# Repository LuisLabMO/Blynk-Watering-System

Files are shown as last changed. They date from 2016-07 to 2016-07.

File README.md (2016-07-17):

# Smart Modular Watering System using Blynk

I like plants, I like to be eco-friendly, love electronics, but how can I fit those things together? enters the **Smart Modular Watering System**.

Smart Modular Watering System using Blynk - Youtube (https://youtu.be/UPALH_MEa6o)

Using the [SparkFun ESP8266 Blynk Board](https://www.sparkfun.com/products/13794) with the [Blynk app](http://www.blynk.cc) you can build a system that monitors the level of the water reservoir and will water your plants automatically at the right moment.

> **It will help you save water!**

## Sensors data

Data collected from sensors is used to decide when is the right time to water the plants, to send alerts when the water reservoir is low and more:

* **Soil moisture sensor**: accurately measures the actual soil moisture.
* An **ultrasonic distance sensor** will measure the level of the water reservoir with good reliability.
* **UV sensor** data may help deciding whether your plant needs more shadow or direct sunlight.
* **Temperature** and **humidity** sensors can also help deciding about critical conditions for your plants.

## Operation - The Blynk App

The Blynk app can be used to monitor in real time the data collected by the sensors:
* Plot the UV index.
* Monitor the water level, temperature, humidity, soil moisture in real time.
* Check the status of the irrigation system (On/Off) - **H2O Led**.

Some parameters of the system can be modified by using the Blynk app too:
* **Water level threshold**: if the water level is above¹ this number, the app will send a warning.
* **Soil moisture threshold**: the system will turn On the irrigation if the current soil moisture is below this number.
* **Watering interval _(in hours)_**: how often the system will irrigate -if conditions require it-.
* **Watering time _(in seconds)_**: duration of the irrigation when activated.

> ¹Please note that the water level sensor measures the distance between the top of the container and the surface of the water. So a higher number means a lower water level.

## Make it Modular, Make it Smarter

The **Smart Modular Watering System** has a very simple implementation, but there is lot of room for improvement. Some other features can be added to the **Smart Modular Watering System** with some more work, these are just a few examples:

* The **UV sensor** data can also be used to decide at what times of the day to stop watering. *Maybe stop watering at night?*
* The data collected can be analyzed to predict the water usage. e.g.: *How much water your plants will need before your next trip.*
* Add a solar panel, charge your batteries with it and show the world that you care about the Environment!.

## Repository Contents

* [/3D_Models](https://github.com/LuisLabMO/Blynk-Watering-System/tree/master/3D_Models) - SketchUp and **.STL** files
* [/ATtiny45_HC-SR04_to_I2C_Source_Code](https://github.com/LuisLabMO/Blynk-Watering-System/tree/master/ATtiny45_HC-SR04_to_I2C_Source_Code) - Source code for the ATtiny45 used to convert the data from ultrasonic distance sensor to I2C.
* [/Blynk_Board_Source_Code](https://github.com/LuisLabMO/Blynk-Watering-System/tree/master/Blynk_Board_Source_Code) - Source code for the [SparkFun ESP8266 Blynk Board](https://www.sparkfun.com/products/13794)
* [/Hardware](https://github.com/LuisLabMO/Blynk-Watering-System/tree/master/Hardware) - Eagle design files: **.BRD**, **.SCH**

## More Information

For more information visit the project page on [Hackster.io](https://www.hackster.io/lmortizg/smart-modular-watering-system-b571ec)

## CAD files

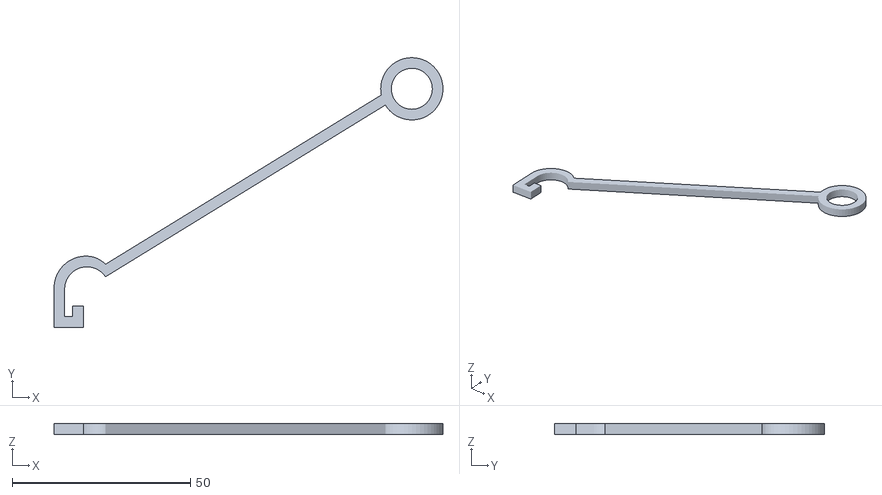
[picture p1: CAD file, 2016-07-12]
3D_Models/Tubing bracket for window planter.stl
109.2 x 75.7 x 3.00

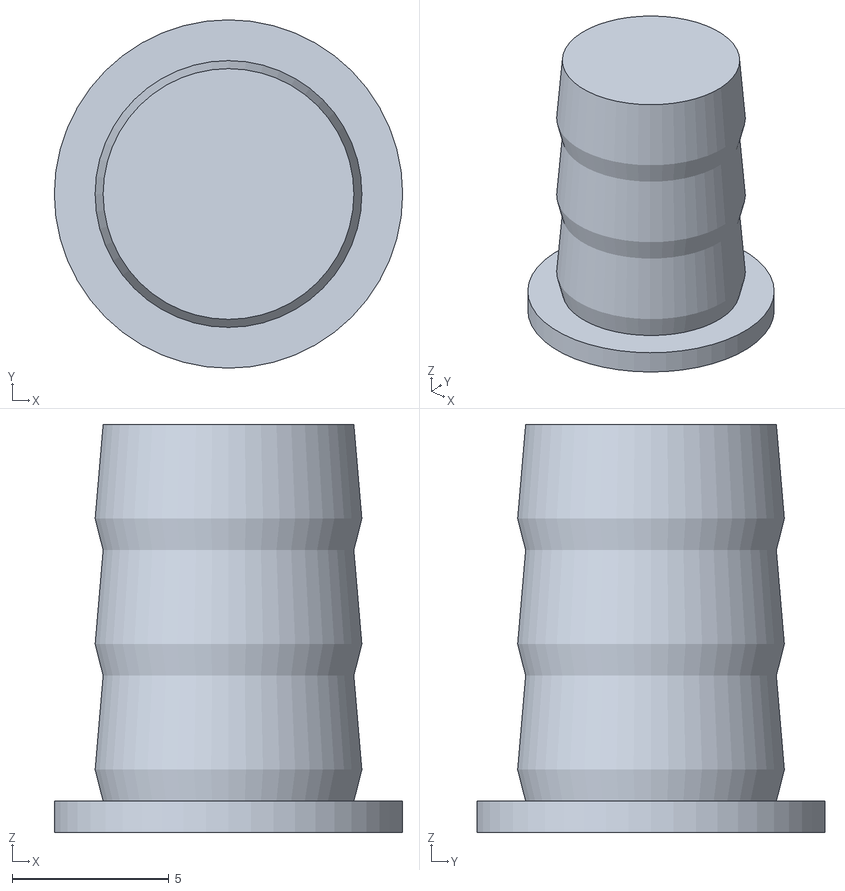
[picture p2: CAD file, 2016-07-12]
3D_Models/Clear Tube End Cap 5_16.stl
11.1 x 11.1 x 13.0

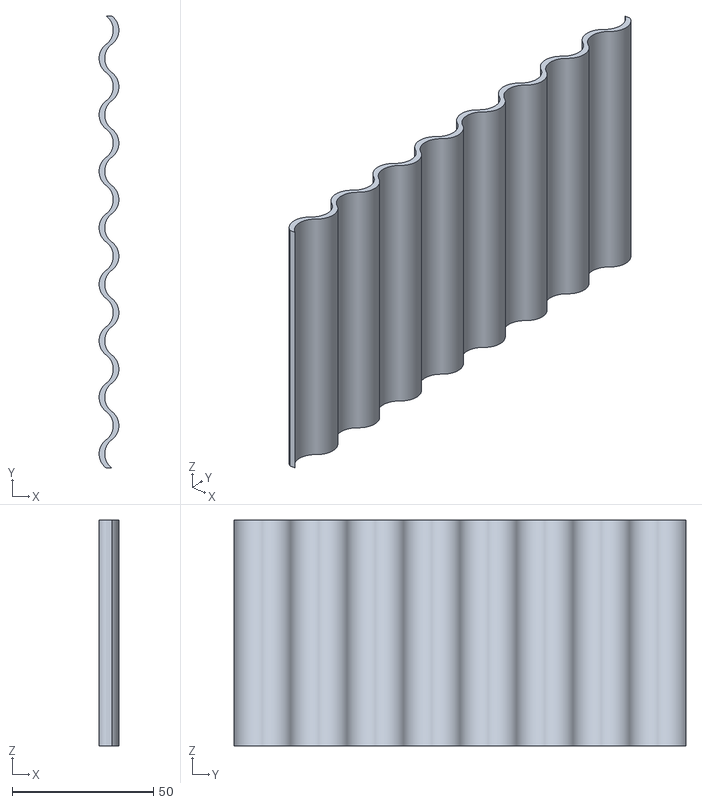
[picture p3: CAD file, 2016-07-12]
3D_Models/Blynk Smart Modular Water System roof.stl
7.00 x 160.0 x 80.0

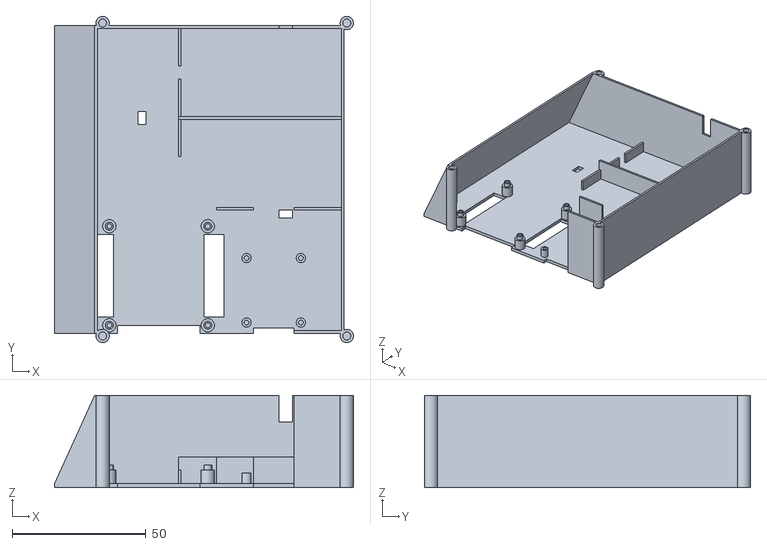
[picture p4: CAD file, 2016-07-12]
3D_Models/Blynk Smart Modular Water System mount.stl
111.8 x 122.0 x 34.5

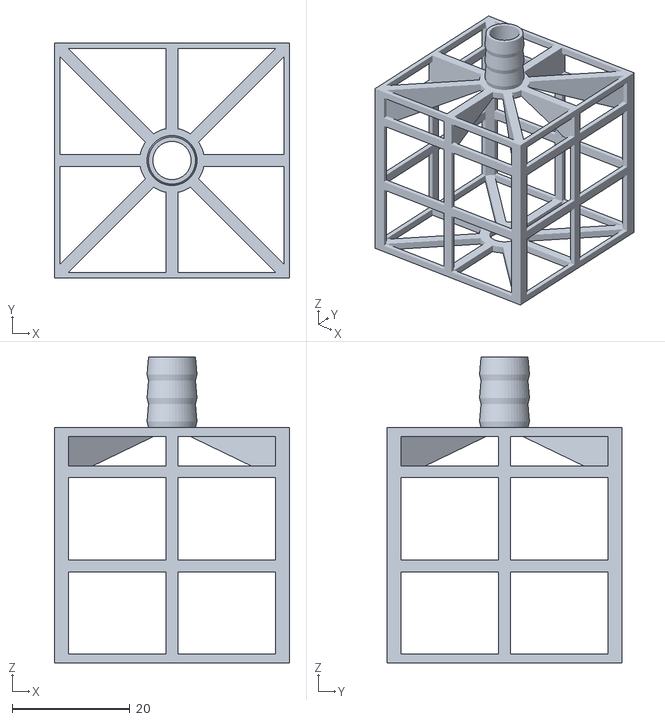
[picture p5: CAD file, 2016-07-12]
3D_Models/Cage cube for water filter 5_16.stl
40.0 x 40.0 x 52.0

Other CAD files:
3D_Models/Blynk Smart Modular Water System mount.skp
3D_Models/Blynk Smart Modular Water System roof.skp
3D_Models/Cage cube for water filter 5_16.skp
3D_Models/Clear Tube End Cap 5_16.skp
3D_Models/Tubing bracket for window planter.skp

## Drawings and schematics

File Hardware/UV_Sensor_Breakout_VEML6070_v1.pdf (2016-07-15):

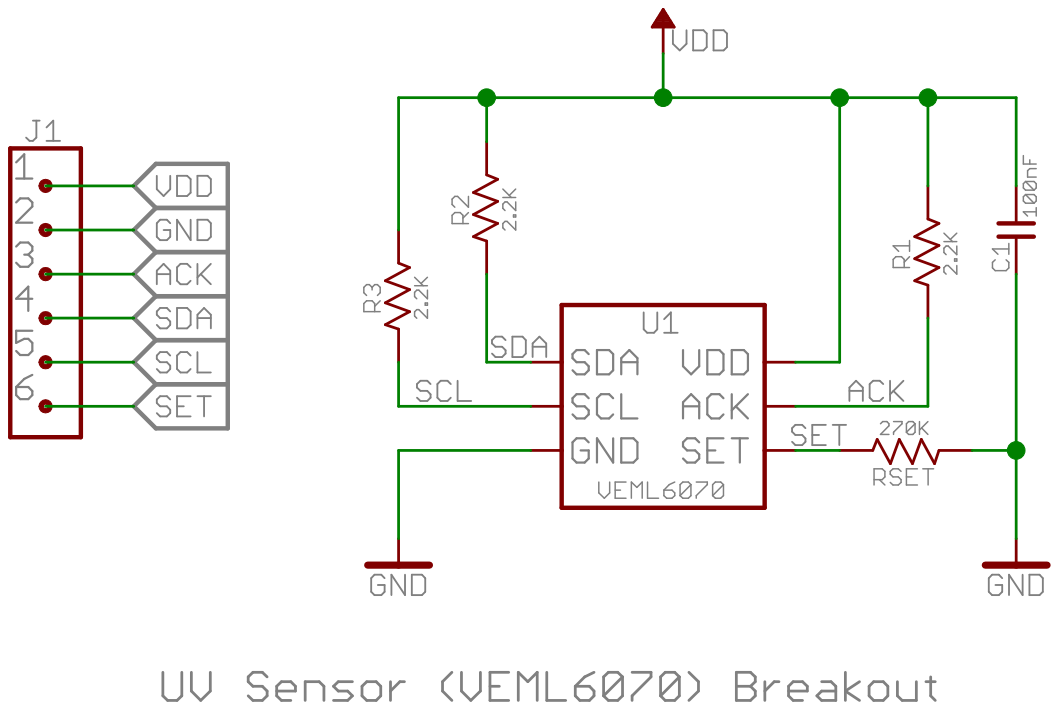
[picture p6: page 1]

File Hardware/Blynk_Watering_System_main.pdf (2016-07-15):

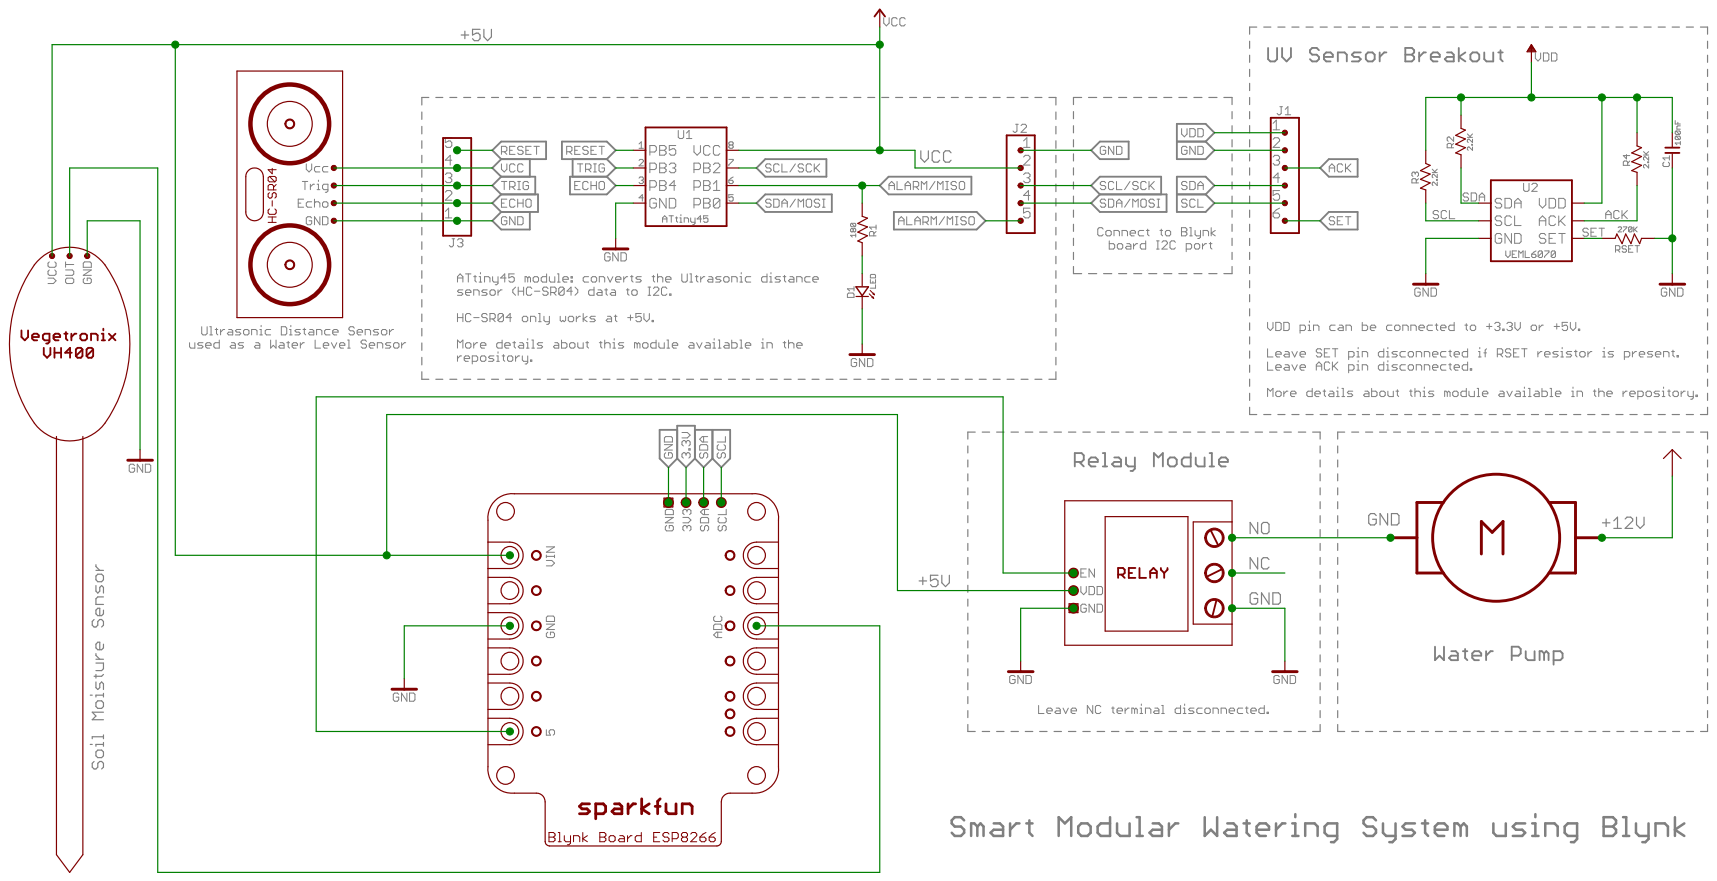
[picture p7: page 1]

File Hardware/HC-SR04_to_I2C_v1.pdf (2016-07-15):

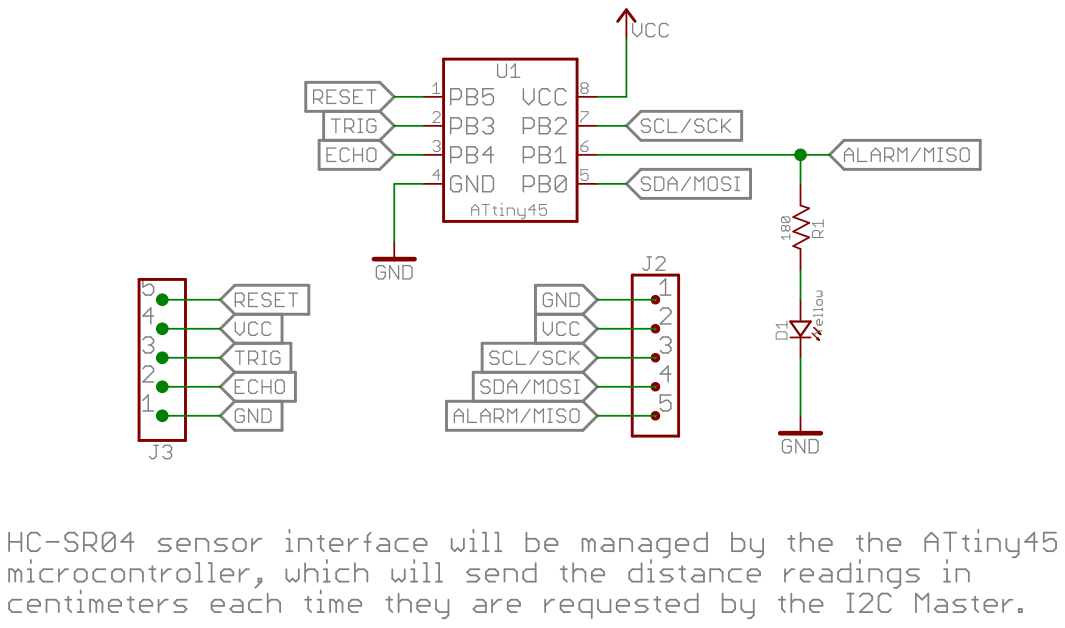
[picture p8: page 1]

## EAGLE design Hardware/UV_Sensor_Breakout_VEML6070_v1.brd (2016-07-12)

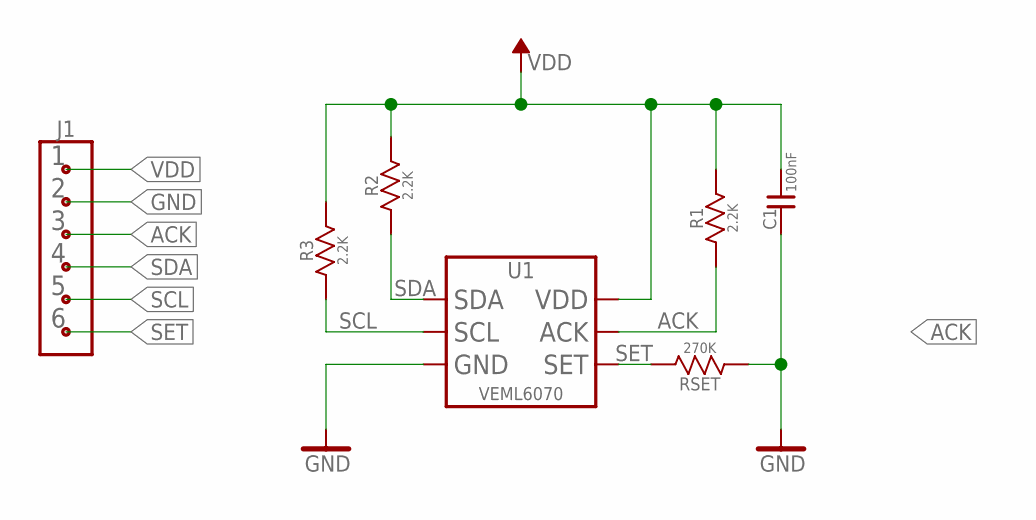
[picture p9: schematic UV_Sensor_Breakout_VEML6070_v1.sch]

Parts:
C1: 100nF; 0603[1608]
J1: PIN_HEADER_1X06_0.1"_STR_G[2]_PTH
R1, R2, R3: 2.2K; 0603[1608]
RSET: 270K; 0603[1608]
U1: VEML6070; OPLGA

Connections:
ACK: J1.3, R1.1, U1.2 (ACK)
GND: C1.1, J1.2, RSET.1, U1.1 (GND)
SCL: J1.5, R3.1, U1.5 (SCL)
SDA: J1.4, R2.1, U1.3 (SDA)
SET: J1.6, RSET.2, U1.4 (SET)
VDD: C1.2, J1.1, R1.2, R2.2, R3.2, U1.6 (VDD)

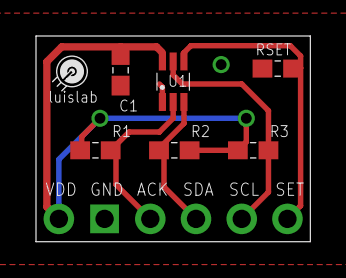
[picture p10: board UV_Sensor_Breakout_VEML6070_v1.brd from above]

Board: 2 copper layers, 15.2 x 11.4 mm, 7 parts (1 on the bottom side), 6 nets.

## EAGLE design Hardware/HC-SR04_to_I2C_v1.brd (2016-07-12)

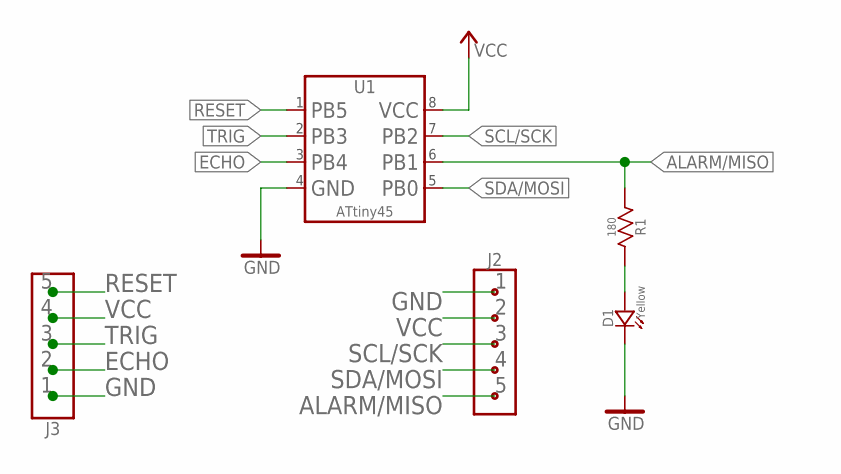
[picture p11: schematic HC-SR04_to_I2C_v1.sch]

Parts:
D1: Yellow; 0805[2012]
J2, J3: PIN_HEADER_1X05_0.1"_STR_G[1]_PTH
R1: 180; 0603[1608]
U1: ATtiny45; TSSOP_MO-153-AC

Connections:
ALARM/MISO: J2.5, R1.1, U1.6 (PB1)
ECHO: J3.2, U1.3 (PB4)
GND: D1.-, J2.1, J3.1, U1.4 (GND)
unnamed: D1.+, R1.2
RESET: J3.5, U1.1 (PB5)
SCL/SCK: J2.3, U1.7 (PB2)
SDA/MOSI: J2.4, U1.5 (PB0)
TRIG: J3.3, U1.2 (PB3)
VCC: J2.2, J3.4, U1.8 (VCC)

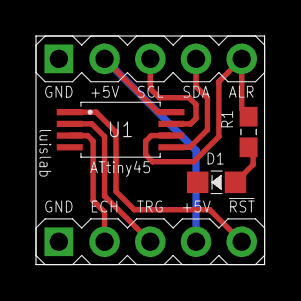
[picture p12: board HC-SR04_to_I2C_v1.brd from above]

Board: 2 copper layers, 12.7 x 12.7 mm, 5 parts (0 on the bottom side), 9 nets.

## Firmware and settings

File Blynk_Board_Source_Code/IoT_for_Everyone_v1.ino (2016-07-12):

#define BLYNK_PRINT Serial    // Comment this out to disable prints and save space
#include <ESP8266WiFi.h>
#include <BlynkSimpleEsp8266.h>
#include <SparkFunHTU21D.h> // Temperature and Humidity Sensor
#include <Wire.h>
#include <EEPROM.h>

////////////////////////////////////
// Blynk Virtual Variable Mapping //
////////////////////////////////////
#define VIRTUAL_LED                    V1 //This LED will indicate when the watering system is on/off in the app.
#define VIRTUAL_TEMPERATURE_F          V5
#define VIRTUAL_TEMPERATURE_C          V6
#define VIRTUAL_HUMIDITY               V7

#define VIRTUAL_WATERING_TIME          V10
#define VIRTUAL_WATERING_INTERVAL      V13

#define VIRTUAL_UV_INDEX               V19
#define VIRTUAL_WATER_LEVEL            V22
#define VIRTUAL_MOISTURE_THRESHOLD     V25
#define VIRTUAL_WATER_LEVEL_THRESHOLD  V26

#define VIRTUAL_RUNTIME                V30

////////////////////
// Blynk Settings //
////////////////////
char BlynkAuth[] = "blynkAuthToken";
char WiFiNetwork[] = "SSID";
char WiFiPassword[] = "WiFiPassword";

///////////////////////
// Hardware Settings //
///////////////////////
#define WS2812_PIN 4 // Pin connected to WS2812 LED
#define BUTTON_PIN 0
#define LED_PIN    5
HTU21D thSense;

////////////////////////
// Sensors settings   //
////////////////////////
#define VEML6070_ADDRESS_WRITE (0x70 >> 1)     // Address of UV Sensor VEML6070 Write 0x38h

#define VEML6070_ADDRESS_READ_MSB (0x73 >> 1)  // Address of UV Sensor VEML6070 MSB 0x39h
#define VEML6070_ADDRESS_READ_LSB (0x70 >> 1)  // Address of UV Sensor VEML6070 LSB 0x38h

#define HCSR04_ADDRESS 0x74                    // Address of Ultrasonic Sensor HC-SR04 (Water Level)

//////////////////////////
// Hardware Definitions //
//////////////////////////
uint8_t selfTestResult = 0;

//////////////////////////
// Variable Definitions //
//////////////////////////
bool firstConnect = true;

bool notifyFlag = false;

uint8_t wireR[2] = {0, 0};
uint16_t uvIndex = 0;

uint8_t waterLevel = 0;
uint8_t waterLevelThreshold = 20;  //Low Water Level: anything above or equal to this number is considered low water level.
uint16_t moistureThreshold = 520;   //Plant(s) will be watered if soil moisture is below this value.
uint16_t moisture = 0;

long lastWateringTime;
long wateringInterval = 60 * 60 * 1000; //How often system checks if plant(s) require water
long wateringTime = 15 * 1000;          //The amount of time sprinkler will be watering each time -in milliseconds-.
bool watering = false;                  //Watering system is currently On/Off (true/false).

long lastMeasuringTime;
long measuringInterval = 5 * 1000;      // How often system reads some sensors values in milliseconds

WidgetLED led1(VIRTUAL_LED); // LED widget in Blynk App

void setup()
{
  // Initialize hardware
  Serial.begin(9600); // Serial
  pinMode(BUTTON_PIN, INPUT); // Button input
  pinMode(LED_PIN, OUTPUT); // LED output

  // Initialize Blynk
  Blynk.begin(BlynkAuth, WiFiNetwork, WiFiPassword);
  while (Blynk.connect() == false) {
    // Wait until connected
  }

  /////////////////
  // Si7021 Test //
  /////////////////
  thSense.begin();
  if (scanI2C(0x40)) { // Si7021 is i2c address 0x40
    Serial.println("Si7021 test succeeded");
    selfTestResult |= (1 << 1);
  }else
    Serial.println("Si7021 test failed");

  Wire.beginTransmission(VEML6070_ADDRESS_WRITE);
  Wire.write(0b00000110); // 1T
  Wire.endTransmission();
  Serial.println("UV Sensor VEML6070 Initialized");

  lastWateringTime = millis() - wateringInterval + 20000; // system will start checking moisture 15 seconds after being turned on
  lastMeasuringTime = millis() - measuringInterval;
}

void loop() {
  if ( millis() - lastMeasuringTime >= measuringInterval ) { //Read sensor values that are required for decision making
    Wire.requestFrom(HCSR04_ADDRESS, 1);
    while ( Wire.available() )
      waterLevel = Wire.read();
    lastMeasuringTime = millis();
    //Serial.println("Water level:" + String(waterLevel));
  }

  if ( !watering ) {
    if ( millis() - lastWateringTime >= wateringInterval ) {
      Serial.println("Water level: " + String(waterLevel));
      Serial.println("UV Index: " + String(uvIndex));

      notifyFlag = false;                            //to avoid repeating notifications, reset flag after each watering interval.
      moisture = analogRead(A0);

      if ( moisture < moistureThreshold ) {
        Serial.println("Moisture reading (" + String(moisture) + ") below Moisture threshold (" + String(moistureThreshold) + ").");
        Serial.println("Watering plant(s) for " + String(wateringTime / 1000) + " seconds.");

        watering = true;
        led1.on(); // Turn the H2O LED on in the app
        digitalWrite(LED_PIN, HIGH);        
      }else {
        Serial.println("Soil moisture (" + String(moisture) + ") OK. Plant(s) do not need water at this time.");
      }
      lastWateringTime = millis();
    }
  }else { //Watering plant(s)
    if ( millis() - lastWateringTime >= wateringTime ) {
        Serial.println("Sprinkler system is Off.");
        watering = false;
        lastWateringTime = millis();
        led1.off(); // Turn the H2O LED off in the app
        digitalWrite(LED_PIN, LOW);        
    }      
  }

  if ( waterLevel >= waterLevelThreshold ) {
    if ( !notifyFlag ) {
      Blynk.notify("Water level is running low."); // Notify!
      Serial.println("Water level (" + String(waterLevel) + ") above threshold (" + String(waterLevelThreshold) + "). Water level is running low.");
      notifyFlag = true;
    }
  }

  // Execute Blynk.run() as often as possible during the loop
  Blynk.run();
}


// Check for a response from an I2C device
bool scanI2C(uint8_t address) {
  Wire.beginTransmission(address);
  Wire.write( (byte)0x00 );
  if (Wire.endTransmission() == 0)
    return true;
  return false;
}

// Value ranges are ignored once values are written
// Board runs hot, subtract an offset to try to compensate:
float tempCOffset = 0; //-8.33;
BLYNK_READ(VIRTUAL_TEMPERATURE_F) {
  float tempC = thSense.readTemperature(); // Read from the temperature sensor
  tempC += tempCOffset; // Add any offset
  float tempF = tempC * 9.0 / 5.0 + 32.0; // Convert to farenheit
  // Create a formatted string with 1 decimal point:
  Blynk.virtualWrite(VIRTUAL_TEMPERATURE_F, tempF); // Update Blynk virtual value
}

BLYNK_READ(VIRTUAL_TEMPERATURE_C) {
  float tempC = thSense.readTemperature(); // Read from the temperature sensor
  tempC += tempCOffset; // Add any offset
  Blynk.virtualWrite(VIRTUAL_TEMPERATURE_C, tempC); // Update Blynk virtual value
}

BLYNK_READ(VIRTUAL_HUMIDITY) {
  float humidity = thSense.readHumidity(); // Read from humidity sensor
  Blynk.virtualWrite(VIRTUAL_HUMIDITY, humidity); // Update Blynk virtual value
}

BLYNK_WRITE(TEMP_OFFSET_VIRTUAL) { // Very optional virtual to set the tempC offset

  tempCOffset = param.asInt();
}

BLYNK_WRITE(VIRTUAL_WATERING_TIME) {
  int inputThreshold = param.asInt();

  wateringTime = constrain(inputThreshold, 10, 30) * 1000; // converting to milliseconds
  notifyFlag = false;

  Serial.println("Watering time set to: " + String(wateringTime / 1000) + " seconds.");
}

BLYNK_WRITE(VIRTUAL_WATERING_INTERVAL) {
  int inputThreshold = param.asInt();

  wateringInterval = constrain(inputThreshold, 1, 5) * ( 60 * 60 * 1000 ); //converting to milliseconds
  notifyFlag = false;

  Serial.println("Watering interval set to every " + String(wateringInterval / (60 * 60 * 1000)) + " hour(s).");
}

BLYNK_READ(VIRTUAL_UV_INDEX) {
  wireR[0] = 0;
  wireR[1] = 0;  
  uvIndex = 0;

  Wire.requestFrom(VEML6070_ADDRESS_READ_MSB, 1);
  while ( Wire.available() )
    wireR[0] = Wire.read();

  Wire.requestFrom(VEML6070_ADDRESS_READ_LSB, 1);
  while ( Wire.available() )
    wireR[1] = Wire.read();

  uvIndex = wireR[0] << 8;
  uvIndex |= wireR[1];

  Blynk.virtualWrite(VIRTUAL_UV_INDEX, uvIndex); // Update Blynk virtual value
}

BLYNK_READ(VIRTUAL_WATER_LEVEL) { //this value is refreshed in the loop since it is used for decision making.
  
  Blynk.virtualWrite(VIRTUAL_WATER_LEVEL, waterLevel); // Update Blynk virtual value
}

BLYNK_WRITE(VIRTUAL_MOISTURE_THRESHOLD) {
  int inputThreshold = param.asInt();

  moistureThreshold = constrain(inputThreshold, 1, 1024);
  notifyFlag = false;

  Serial.println("Moisture threshold set to: " + String(moistureThreshold));
}

BLYNK_WRITE(VIRTUAL_WATER_LEVEL_THRESHOLD) {
  int inputThreshold = param.asInt();

  waterLevelThreshold = constrain(inputThreshold, 1, 255);
  notifyFlag = false;

  Serial.println("Water level threshold set to: " + String(waterLevelThreshold));
}

BLYNK_CONNECTED() {
  if ( firstConnect ) {
    // Two options here. Either sync values from phone to Blynk Board:
    //Blynk.syncAll(); // Uncomment to enable.
    // Or set phone variables to default values of the globals:
    Blynk.virtualWrite(VIRTUAL_MOISTURE_THRESHOLD, moistureThreshold);
    Blynk.virtualWrite(VIRTUAL_WATER_LEVEL_THRESHOLD, waterLevelThreshold);
    Blynk.virtualWrite(VIRTUAL_WATERING_TIME, wateringTime / 1000); //Converting from milliseconds to seconds.
    Blynk.virtualWrite(VIRTUAL_WATERING_INTERVAL, wateringInterval / ( 60 * 60 * 1000) ); //Converting from milliseconds to hours
    //Blynk.notify("Smart Modular Watering System Ready!"); // Notify!
    firstConnect = false;
  }
}

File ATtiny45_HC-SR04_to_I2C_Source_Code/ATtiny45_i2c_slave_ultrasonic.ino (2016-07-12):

// Code for the ATtiny (Slave)
//
// Luis Ortiz - luislab.com
// July 3, 2016
// This program is designed to use an ATtiny45 (or compatible) microcontroller 
// to read the water level of a container using an ultrasonic range finder HC-SR04.
// - Readings will be pushed through I2C
// - alarmPin: HIGH if the water level exceeds a threshold.
// - alarmPin: HIGH if sensor readings not between min and max range (this may be
//             useful to detect problems with the sensor.


#define I2C_SLAVE_ADDRESS 0x74 // Address of the slave

#define echoPin 4 // Echo Pin
#define trigPin 3 // Trigger Pin
#define LEDPin 1  // Onboard LED Pin / alarmPin

// As safety method, all measurements will be constrained to min and max range.
#define maxRange 100 // Maximum range
#define minRange 2   // Minimum range

#define waterThreshold 25 // Critical Water Level

#include <TinyWireS.h> //https://github.com/rambo/TinyWire

uint8_t distance = 0;
long duration; // Duration used to calculate distance

long lastMicros = 0;

long microsONDelay = 10;
long microsOFFDelay = 50000;

int lastTrig;

void setup() {
  TinyWireS.begin(I2C_SLAVE_ADDRESS);
  TinyWireS.onRequest(sendDistance);

  pinMode(trigPin, OUTPUT);
  pinMode(echoPin, INPUT);
  digitalWrite(trigPin, LOW);
  lastTrig = LOW;
  lastMicros = micros();

  pinMode(LEDPin, OUTPUT); //PB1
  digitalWrite(LEDPin, LOW);
}

void loop() {
  if ( lastTrig == LOW ) {
    if ((micros() - lastMicros) >= microsOFFDelay) {
      digitalWrite(trigPin, HIGH);
      lastMicros = micros();
      lastTrig = HIGH;
    }
  }else if ( lastTrig == HIGH ) {
    if ((micros() - lastMicros) >= microsONDelay) {
      digitalWrite(trigPin, LOW);
      duration = pulseIn(echoPin, HIGH);
      lastMicros = micros();
      lastTrig = LOW;
  
      //Calculate the distance (in cm) based on the speed of sound.
      distance = constrain(duration/58.2, minRange, maxRange);
    
      if ( distance >= maxRange || distance <= minRange ) {
        digitalWrite(LEDPin, HIGH);
      }else {
        if ( distance >= waterThreshold )
          digitalWrite(LEDPin, HIGH);
        else
          digitalWrite(LEDPin, LOW);
      }
    }
  }

  TinyWireS_stop_check();
}

void sendDistance() {
  TinyWireS.send(distance);
}

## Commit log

2016-07-12 3D Models, Source code and eaglecad files created.
    [Blynk Smart Modular Water System mount.skp, Blynk Smart Modular Water System mount.stl, Blynk Smart Modular Water System roof.skp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]
2016-07-15 Added schematic .PDF
2016-07-15 Minor fixes
    [Blynk_Watering_System_main.brd, Blynk_Watering_System_main.sch, HC-SR04_to_I2C_v1.sch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]
2016-07-15 Legend added
    [UV_Sensor_Breakout_VEML6070_v1.sch]
2016-07-16 Removed. Not required
    [Blynk_Watering_System_main.brd]
